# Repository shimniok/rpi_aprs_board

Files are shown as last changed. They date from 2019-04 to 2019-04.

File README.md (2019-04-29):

# Raspberry Pi APRS Interface Board

This board is designed to inteface a 2M ham radio with a Raspberry Pi running APRS software such as 
[direwolf](https://github.com/wb2osz/direwolf). Features DCD (Data Carrier Detect) and PTT (Push-To-Talk) GPIO and indicator 
LEDs.

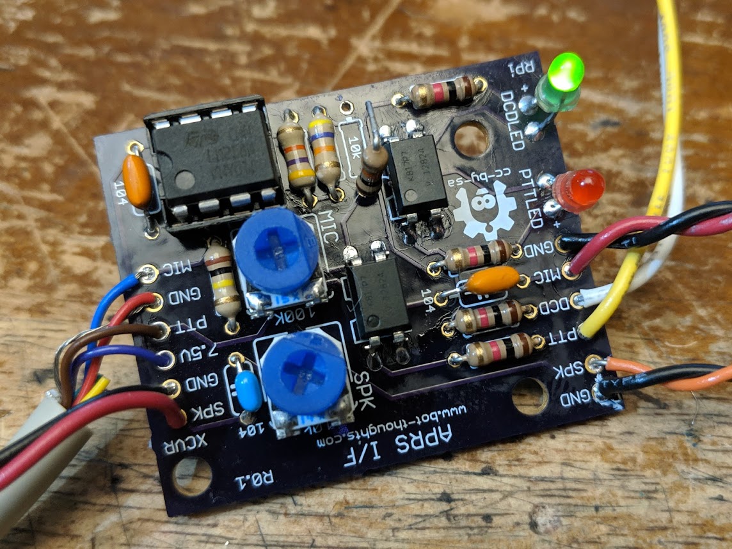
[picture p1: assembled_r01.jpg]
board photo Assembled Board R0.1


I built this board for use with a Radio Shack HTX-212 I picked up cheap at a hamfest.

# HTX-212 Pinout

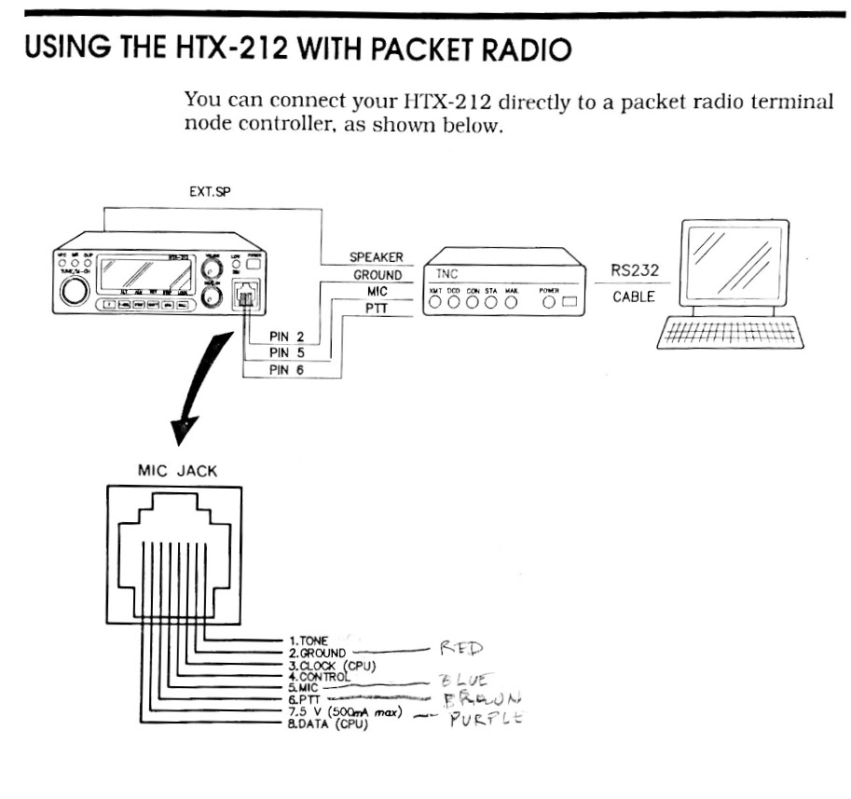
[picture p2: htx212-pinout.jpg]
HTX-212 Pinout HTX-212 Packet Pinout


On the "XCVR" side of the board, solder jumper wires into wire pads labeled SPK/GND, and solder the other ends to a 3.5mm 
audio jack. Use a 3.5mm audio cable (mono is fine) to connext the radio's external speaker to this SPK jack. Use an RJ45 mic 
cable in the Mic jack of the radio and connect the 5V, PTT, MIC, and GND wire pads to the appropriate wires per the pinout 
image above and as below.

 * Pin 2 - GND
 * Pin 5 - MIC
 * Pin 6 - PTT
 * Pin 7 - 5V

# Raspberry Pi Hookup

You'll need an audio board with mic and speaker/headphone jack(s). You can either use a USB audio board or one that plugs 
into the RPi GPIO pins like these:

 * [Adafruit I2S Audio Bonnet](https://www.adafruit.com/product/4037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)
 * [Fe-Pi Audio Z (V2)](https://pinout.xyz/pinout/fe_pi_audio_z_v2)

Using jumper wire soldered into wire pads on the "RPi" side of the board, connect the MIC/GND to an 3.5mm audio jack, connect 
SPK/GND to another 3.5mm audio jack. Use two 3.5mm audio cables to connect to your audio board as follows. MIC goes to RPi 
mic jack. SPK goes to RPi external speaker jack. Then, solder jumper wire to the DCD and PTT wire pads, and connect to 
active high pins on the Raspberry Pi. I use GPIO17 and GPIO27. Ground is provided through the audio cables

# Adjusting Audio Levels

Adjust the MIC and SPK potentiometers in the middle. Now boot your Raspberry Pi and turn on your radio with an antenna 
attached and tune to 144.390MHz (APRS frequency). Launch direwolf after installing and setting up your direwolf.conf per the 
Direwolf User Guide. For now, disable beaconing.

## Adjust radio output level

Adjust radio volume and the SPK potentiometer until direwolf reports audio level of about 50 for most stations.  

## Adjust radio input level

You'll need an oscilloscope for this. Tune the radio to an unused packet band. Stop direwolf and reconfigure it to transmit 
every 5 seconds, and restart. Use the oscilloscope probe to display the waveform at the XCVR MIC output wirepad. Adjust the 
MIC potentiometer as high as it will go without clipping the peak of the signal.

You may need to adjust the Raspberry Pi's output level. Keep in mind that USB audio boards may "forget" alsamixer levels you
set should the board become unplugged.

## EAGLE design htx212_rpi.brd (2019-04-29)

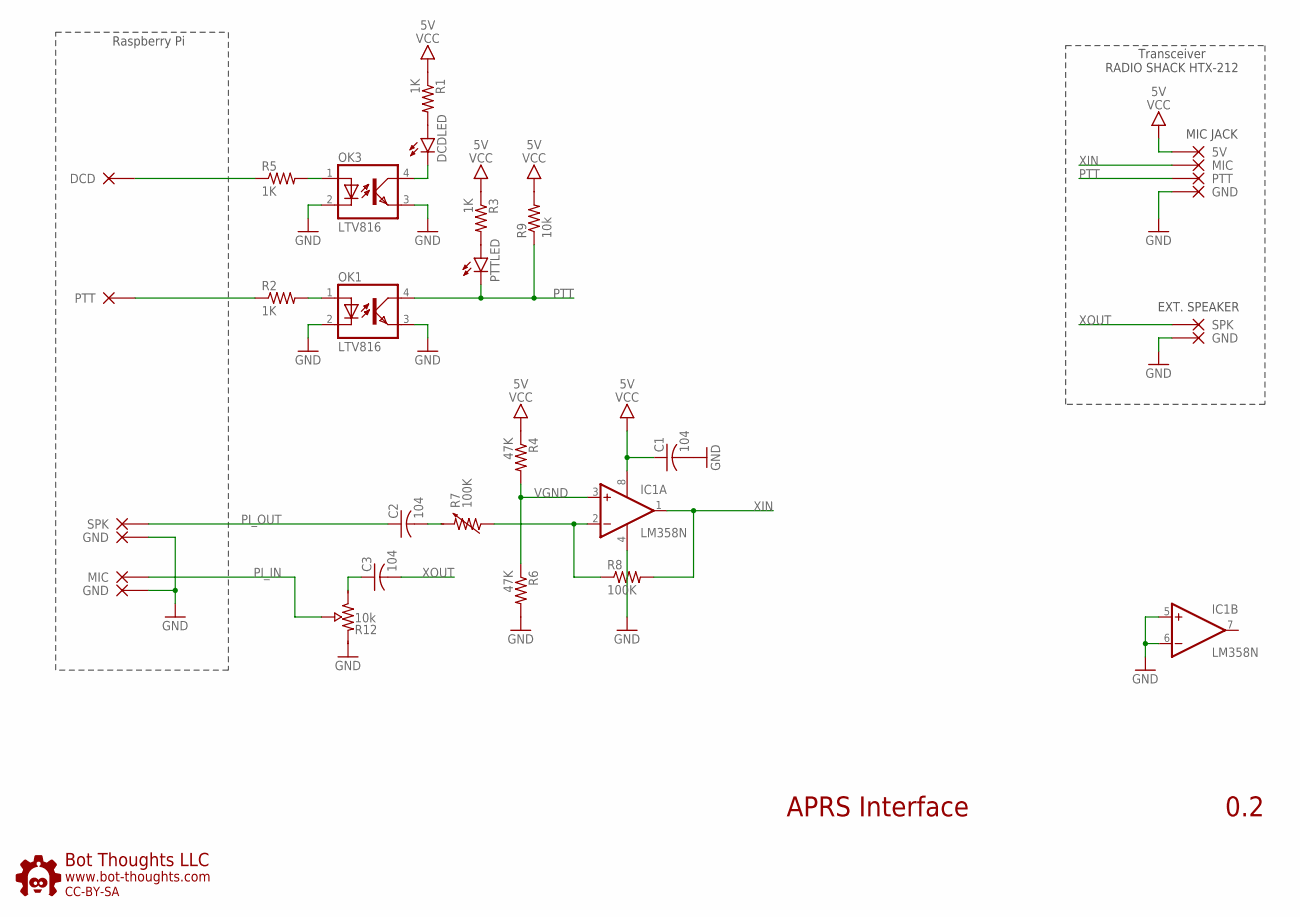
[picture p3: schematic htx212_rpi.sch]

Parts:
C1, C2: 104; C075
C3: 104; C050
DCDLED: LED5MMRA
IC1: LM358N; DIL08
OK1, OK3: LTV816; DIL04
PTTLED: LED5MMRA
R1, R2, R3, R5: 1K; 0204/7
R4, R6: 47K; 0204/7
R7: 100K; CA6V
R8: 100K; 0204/7
R9: 10k; 0204/7
R12: 10k; CA6V
U$3: BTLOGO-LOGO-MD; BTLOGOM
X1, X7: MIC; PAD_22GA
X2, X5, X8, X13: GND; PAD_22GA
X3: PTT; PAD_22GA
X4: 5V; PAD_22GA
X6, X12: SPK; PAD_22GA
X9: PTT; PAD_24GA
X15: DCD; PAD_24GA

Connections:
DCD_CTL: R5.1, X15.P$1
GND: C1.2 (-), IC1.4 (V-), IC1.5 (+IN), IC1.6 (-IN), OK1.2 (C), OK1.3 (EMIT), OK3.2 (C), OK3.3 (EMIT), R6.2, R12.E (B), X2.P$1, X5.P$1, X8.P$1, X13.P$1
unnamed: OK1.1 (A), R2.2
unnamed: DCDLED.A, R1.2
unnamed: DCDLED.C, OK3.4 (COL)
unnamed: PTTLED.A, R3.2
unnamed: OK3.1 (A), R5.2
unnamed: C3.1 (+), R12.A
unnamed: IC1.2 (-IN), R7.S (WIPER), R8.1
unnamed: C2.2 (-), R7.E (B)
PI_IN: R12.S (WIPER), X7.P$1
PI_OUT: C2.1 (+), X6.P$1
PTT: OK1.4 (COL), PTTLED.C, R9.1, X3.P$1
PTT_CTL: R2.1, X9.P$1
VCC: C1.1 (+), IC1.8 (V+), R1.1, R3.1, R4.1, R9.2, X4.P$1
VGND: IC1.3 (+IN), R4.2, R6.1
XIN: IC1.1 (OUT), R8.2, X1.P$1
XOUT: C3.2 (-), X12.P$1

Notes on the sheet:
Raspberry Pi
Transceiver RADIO SHACK HTX-212
MIC JACK
EXT. SPEAKER
APRS Interface
0.2

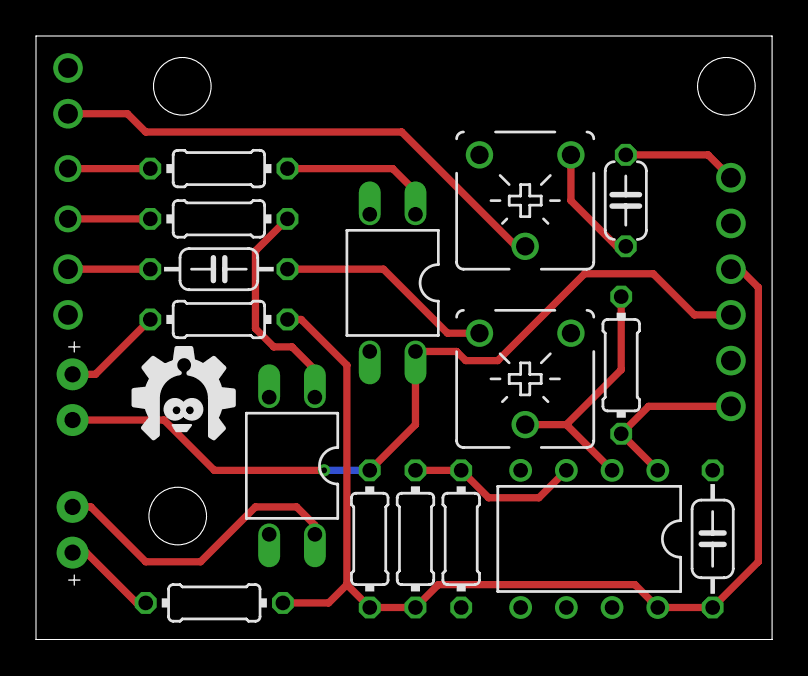
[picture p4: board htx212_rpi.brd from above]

Board: 2 copper layers, 40.9 x 33.5 mm, 31 parts (0 on the bottom side), 18 nets.

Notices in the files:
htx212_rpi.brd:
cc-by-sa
